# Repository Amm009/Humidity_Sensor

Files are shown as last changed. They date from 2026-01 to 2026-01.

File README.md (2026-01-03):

This is a humidity sensor I designed to be installed in the walls of tubs holding 3D printing filament.

The ESP32 wakes from sleep when the touchpad is touched and displays the current humidity and battery level, and then the past humidity level over time with a graph as well.

It can also connect to the internet and be used with MQTT. It reports humidity and battery levels.

AI was used in the development in this code.

Components:
ESP32 (https://www.amazon.com/dp/B0D8T53CQ5) <br/>
AA Battery Tabs (https://www.amazon.com/dp/B077GL8PPJ) <br/>
4 x M3x4x5 Threaded Inserts (https://www.amazon.com/dp/B0F2N8QY45) <br/>
4 x M3x16 Screws (https://www.amazon.com/dp/B0D3X5CT2J) <br/>
SHT31-D Humidity Sensor (https://www.amazon.com/dp/B07ZSZW92J) <br/>
2 x AO3401 P-Channel Mosfet (https://www.amazon.com/dp/B08RHFLH1K) <br/>
2 x AO3400A N-Channel Mosfet (https://www.amazon.com/dp/B0DZHXWCTK) <br/>
2 x 4.7k, 2 x 10k, 2 x 100k SMD Resistors (https://www.amazon.com/dp/B08RYNWTT9) <br/>
1 x Power Switch (https://www.amazon.com/dp/B0DN69L9SG) <br/>
SSD1306 OLED Screen (https://www.amazon.com/dp/B0D2RMQQHR) <br/>
2.54mm Pin Headers (https://www.amazon.com/Ferwooh-Single-Straight-Connector-Spacing/dp/B0CZ6X313F?s=industrial&sr=1-6) <br/>
Buzzer (With the current PCB design, it is inadvisable to use the buzzer. It would also be really annoying if the humidity gets too high with the current code) (https://www.amazon.com/Electromagnetic-Piezo-Buzzer-16ohm-Passive/dp/B097RNHZN4?sr=8-10)
4 x Rechargeable AA's (https://www.amazon.com/EBL-Battery-Rechargeable-Batteries-Foldable/dp/B0FWK97R4W?sr=8-9) <br/>
JST-PH Connectors (https://www.amazon.com/Connector-JST-XH-Connectors-Ratcheting-Crimping/dp/B0CBHL8CMC?sr=8-18) <br/>

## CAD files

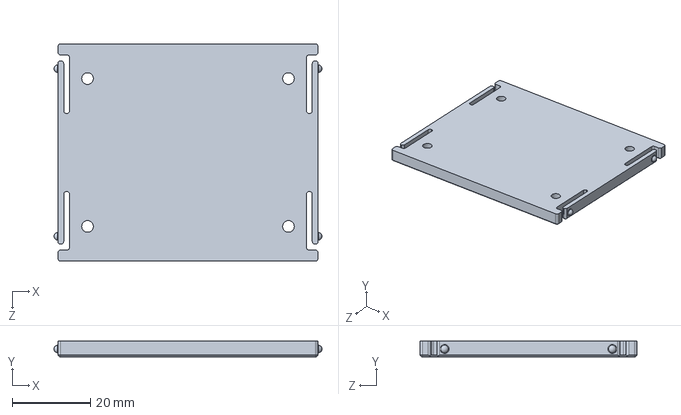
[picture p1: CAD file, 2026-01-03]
3D Models/SolidWorks Files/BatteryDoor.SLDPRT
68.7 x 4.00 x 55.7 mm

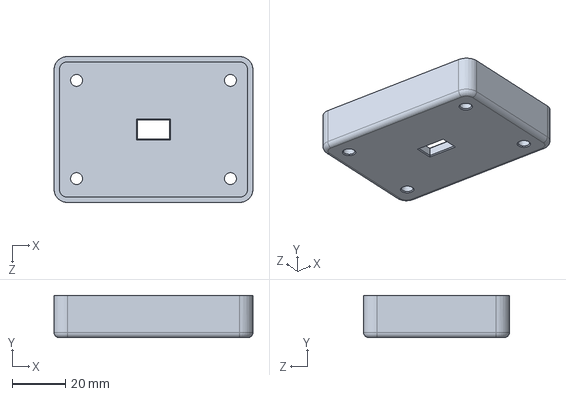
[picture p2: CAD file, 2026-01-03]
3D Models/SolidWorks Files/BottomOfTop.SLDPRT
75.0 x 16.0 x 55.0 mm

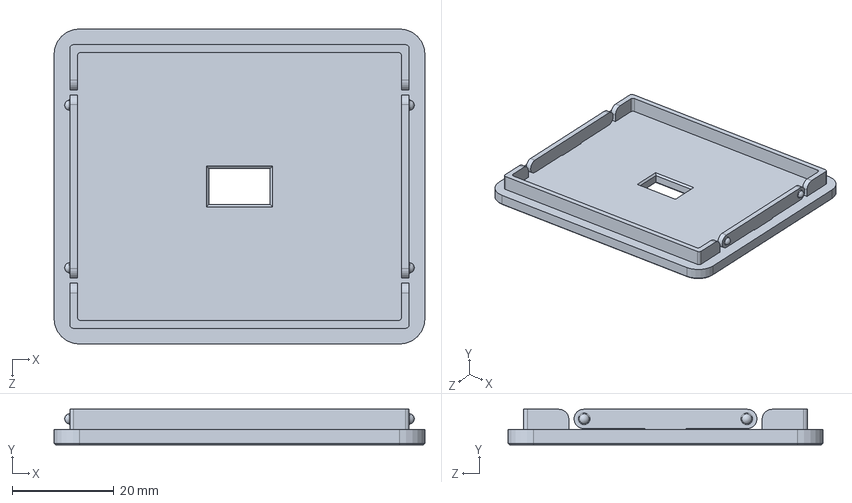
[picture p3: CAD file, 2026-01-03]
3D Models/SolidWorks Files/BatteryHolderTop.SLDPRT
73.0 x 7.00 x 62.0 mm

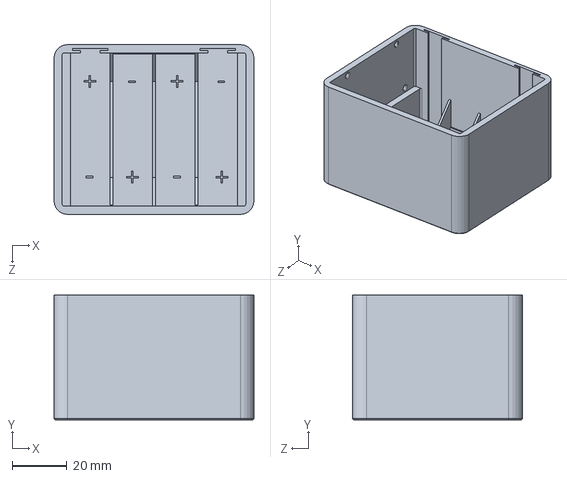
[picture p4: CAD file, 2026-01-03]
3D Models/SolidWorks Files/BatteryHolder.SLDPRT
73.0 x 45.5 x 62.0 mm

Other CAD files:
3D Models/SolidWorks Files/Top.SLDPRT
3D Models/STL Files/BatteryDoor.STL
3D Models/STL Files/BatteryHolder.STL
3D Models/STL Files/BatteryHolderTop.STL
3D Models/STL Files/BottomOfTop.STL
3D Models/STL Files/Top.STL

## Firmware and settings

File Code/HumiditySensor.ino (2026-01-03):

#include <Arduino.h>
#include <Wire.h>
#include "Adafruit_SHT31.h"
#include <SPI.h>
#include <Adafruit_GFX.h>
#include <Adafruit_SSD1306.h>
#include <WiFi.h>
#include <PubSubClient.h>

// --- Network Configuration ---
const char* ssid = "Network Name";
const char* password = "Network Password";
const char* mqtt_server = "Home Server IP";  // IP of your TrueNAS
const int mqtt_port = ;

WiFiClient espClient;
PubSubClient client(espClient);

Adafruit_SHT31 sht31 = Adafruit_SHT31();

#define OLED_RESET -1        // Reset pin # (or -1 if sharing Arduino reset pin)
#define SCREEN_WIDTH 128     // OLED display width, in pixels
#define SCREEN_HEIGHT 64     // OLED display height, in pixels
#define SCREEN_ADDRESS 0x3C  ///< See datasheet for Address; 0x3D for 128x64, 0x3C for 128x32
Adafruit_SSD1306 display(SCREEN_WIDTH, SCREEN_HEIGHT, &Wire, OLED_RESET);

#define uS_TO_S_FACTOR 1000000ULL  // Conversion factor for micro seconds to seconds
#define THRESHOLD 50               // Greater the value, more the sensitivity

int TIME_TO_SLEEP = 3600;  // Time ESP32 will go to sleep (in seconds)
touch_pad_t touchPin;
bool timerEnable = false;
int progTimerStart;
const int timer = 10;
const int R1 = 4680;
const int R2 = 4670;
const int voltagePin = 35;
const int voltEnablePin = 27;
const int buzzerPin = 15;
const int powerEnablePin = 4;
float voltBatt;
float adcVolt;
float h;

// Values for the graph array
const int BUFFER_SIZE = 100;
RTC_DATA_ATTR float buffer[BUFFER_SIZE];
RTC_DATA_ATTR int count = 0;

esp_sleep_wakeup_cause_t wakeup_reason;

void setup() {

  //Start the serial monitor
  Serial.begin(115200);

  //Ensure WiFi is working
  WiFi.begin(ssid, password);
  while (WiFi.status() != WL_CONNECTED) {
    delay(500);
    Serial.print(".");
  }
  Serial.println("WiFi connected");

  // Configure MQTT server address
  client.setServer(mqtt_server, mqtt_port);
  delay(1000);

  // Reconnect if you disconnect
  if (!client.connected()) {
    reconnect();
  }
  client.loop();

  //Set up pins for the voltage sensor and buzzer
  pinMode(buzzerPin, OUTPUT);
  pinMode(voltagePin, INPUT);
  pinMode(voltEnablePin, OUTPUT);
  pinMode(buzzerPin, OUTPUT);
  pinMode(powerEnablePin, OUTPUT);

  digitalWrite(voltEnablePin, HIGH);
  digitalWrite(powerEnablePin, LOW);
  digitalWrite(buzzerPin, LOW);
  delay(100);

  //Set analog read attenuation so that the pin can read the full voltage of the connected battery
  analogSetAttenuation(ADC_11db);

  Wire.begin();

  //Stop the program if something goes wrong with the display
  if (!display.begin(SSD1306_SWITCHCAPVCC, SCREEN_ADDRESS)) {
    Serial.println(F("SSD1306 allocation failed"));
    esp_sleep_enable_timer_wakeup(60 * uS_TO_S_FACTOR);  // Sleep for 60s
    esp_deep_sleep_start();
  }

  //Stop the program if you can't connect to the humidity sensor
  if (!sht31.begin(0x44)) {  // Address 0x44 for SHT31-D
    Serial.println("Couldn't find SHT31 sensor!");
    esp_sleep_enable_timer_wakeup(60 * uS_TO_S_FACTOR);  // Sleep for 60s
    esp_deep_sleep_start();
  }

  touchSleepWakeUpEnable(T9, THRESHOLD);
  print_wakeup_reason();

  //Wake up due to timer, just give warning tones if necessary, and upload humidity and voltage data to the server!
  if (wakeup_reason == ESP_SLEEP_WAKEUP_TIMER) {
    dont_announce_info();
    add_value();

    //Wake up due to touchpad, show information and warnings!
  } else if (wakeup_reason == ESP_SLEEP_WAKEUP_TOUCHPAD) {
    //Show battery voltage and humidity for 10 seconds
    Serial.println("Announcing!");
    announce_info();

    //Show Humidity history graph for 5 seconds
    make_graph();
    going_to_sleep();
  }

  //Turn off external devices
  digitalWrite(voltEnablePin, LOW);
  digitalWrite(powerEnablePin, HIGH);

  //Set the esp to wake up after a defined amount of seconds
  esp_sleep_enable_timer_wakeup(TIME_TO_SLEEP * uS_TO_S_FACTOR);
  Serial.println("ESP32 will now sleep for " + String(TIME_TO_SLEEP) + " Seconds");

  //Go slep (Honk Shoo)
  Serial.flush();
  esp_deep_sleep_start();
}





// Method to print the reason by which ESP32 has been awaken from sleep
esp_sleep_wakeup_cause_t print_wakeup_reason() {
  wakeup_reason = esp_sleep_get_wakeup_cause();
  switch (wakeup_reason) {
    case ESP_SLEEP_WAKEUP_TIMER: Serial.println("Wakeup caused by timer"); break;
    case ESP_SLEEP_WAKEUP_TOUCHPAD: Serial.println("Wakeup caused by touchpad"); break;
  }
  return wakeup_reason;
}

void wakeTone() {
  int frequency = 50;  // Frequency of Middle C in Hz
  int duration = 100;  // Duration in milliseconds

  tone(buzzerPin, frequency, duration);
  delay(duration);  // Wait for the note to finish

  noTone(buzzerPin);  // Stop the tone
}

void sleepTone() {
  int frequency = 50;  // Frequency of Middle C in Hz
  int duration = 100;  // Duration in milliseconds

  tone(buzzerPin, frequency, duration);
  delay(duration);  // Wait for the note to finish

  noTone(buzzerPin);  // Stop the tone
  delay(duration);

  tone(buzzerPin, frequency, duration);
  delay(duration);  // Wait for the note to finish

  noTone(buzzerPin);  // Stop the tone
  delay(duration);

  tone(buzzerPin, frequency, duration);
  delay(duration);  // Wait for the note to finish

  noTone(buzzerPin);  // Stop the tone
  delay(duration);
}

void warning_tone() {
  int frequencyh = 50;  // Frequency of Middle C in Hz
  int frequencyl = 20;  // Frequency of Middle C in Hz
  int duration = 100;   // Duration in milliseconds

  tone(buzzerPin, frequencyh, duration);
  delay(duration);  // Wait for the note to finish

  noTone(buzzerPin);  // Stop the tone
  delay(duration);

  tone(buzzerPin, frequencyl, duration);
  delay(duration);  // Wait for the note to finish

  noTone(buzzerPin);  // Stop the tone
  delay(duration);

  tone(buzzerPin, frequencyh, duration);
  delay(duration);  // Wait for the note to finish

  noTone(buzzerPin);  // Stop the tone
  delay(duration);

  delay(3000);
}
void add_value() {
  if (count < BUFFER_SIZE) {
    // Not full yet → just append
    buffer[count++] = h;
  } else {
    // Full → shift left by 1
    for (int i = 1; i < BUFFER_SIZE; i++) {
      buffer[i - 1] = buffer[i];
    }
    // Add newest value to the end
    buffer[BUFFER_SIZE - 1] = h;
  }
}

void make_graph() {
  display.setTextColor(SSD1306_WHITE);
  display.clearDisplay();
  display.setTextSize(2);
  display.setCursor(2, 0);
  display.println("Hum. Hist.");
  display.setTextSize(1);
  display.setCursor(0, 16);
  display.println("100");
  display.setCursor(5, 35);
  display.println("50");
  display.setCursor(10, 57);
  display.println("0");
  display.drawLine(20, 63, 120, 63, SSD1306_WHITE);
  display.drawLine(20, 63, 20, 16, SSD1306_WHITE);
  display.drawLine(20, 16, 24, 16, SSD1306_WHITE);
  display.drawLine(20, 39, 24, 39, SSD1306_WHITE);
  display.drawLine(20, 51, 22, 51, SSD1306_WHITE);
  display.drawLine(20, 28, 22, 28, SSD1306_WHITE);
  for (int i = 0; i < BUFFER_SIZE; i++) {
    Serial.print(buffer[i]);
    Serial.print(", ");
  }
  Serial.println();  // end the line

  for (int i = 0; i < 100; i++) {
    int x = i + 20;
    int y = map(buffer[i], 0, 100, 63, 13);

    display.drawPixel(x, y, SSD1306_WHITE);
  }
  display.display();
  delay(5000);
}

void get_info() {
  delay(100);
  h = sht31.readHumidity();
  adcVolt = analogReadMilliVolts(voltagePin) / 1000.0;
  voltBatt = adcVolt * (R1 + R2) / R2;
}


void announce_info() {
  get_info();
  //Give a warning if the battery is low
  if (voltBatt <= 4) {
    display.clearDisplay();
    display.setTextColor(SSD1306_WHITE);
    display.setTextSize(2);
    display.setCursor(0, 20);
    display.println("Battery Low");
    display.display();
    warning_tone();
    delay(1000);
  }
  //Give a warning if the humidity is high
  if (h > 25) {
    display.clearDisplay();
    display.setTextColor(SSD1306_WHITE);
    display.setTextSize(2);
    display.setCursor(40, 16);
    display.println("High");
    display.setCursor(18, 38);
    display.println("Humidity");
    display.display();
    warning_tone();
    delay(1000);
  }
  //Display battery and humidity info for 10 seconds
  wakeTone();
  startCountdown();
  while (timerEnable) {
    get_info();
    display.setTextColor(SSD1306_WHITE);
    display.clearDisplay();
    display.setTextSize(2);
    display.setCursor(10, 0);
    display.println("Bt: " + String(voltBatt) + "V");
    display.setTextSize(3);
    display.setCursor(11, 30);
    display.print(String(h) + "%");
    display.display();
    delay(100);
    if (timer - (millis() - progTimerStart) / 1000 <= 0) {
      endCountdown();
    }
  }
}

void going_to_sleep() {
  display.clearDisplay();
  display.setTextSize(2);
  display.setCursor(35, 16);
  display.println("Going");
  display.setCursor(18, 40);
  display.println("to Sleep");
  display.display();
  sleepTone();
  delay(2000);
  display.clearDisplay();
  display.display();
}

//Only give warning tones if necessary, no one's there to look!
void dont_announce_info() {
  get_info();
  if (voltBatt <= 4 || h > 25) {
    warning_tone();
    TIME_TO_SLEEP = 60;
  } else {
    TIME_TO_SLEEP = 60;
  }
  //Send results to MQTT
  char hum[50];
  char volt[50];
  snprintf(hum, 50, "%.0f", h);
  snprintf(volt, 50, "%.2f", voltBatt);
  client.publish("Humidity", hum);
  client.publish("Battery Voltage", volt);
  client.loop();
  delay(100);
}

void startCountdown() {
  if (timerEnable == false) {
    progTimerStart = millis();
    timerEnable = true;
  }
}

void endCountdown() {
  if (timerEnable) {
    timerEnable = false;
  }
}
void reconnect() {
  while (!client.connected()) {
    Serial.print("Attempting MQTT connection...");
    // Attempt to connect (Client ID can be anything unique)
    if (client.connect("ESP32Client")) {
      Serial.println("connected");
    } else {
      Serial.print("failed, rc=");
      Serial.print(client.state());
      Serial.println(" try again in 5 seconds");
      delay(5000);
    }
  }
}

//We not using this...
void loop() {
  // put your main code here, to run repeatedly:
}
